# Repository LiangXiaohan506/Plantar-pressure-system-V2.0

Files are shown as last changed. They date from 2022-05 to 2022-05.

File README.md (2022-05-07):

# Plantar-pressure-system-v2.0
足底压力系统v2.0版本
内容包含硬件和软件
## 软件内容
DMA多通道读取ADC  
基于HAL库的MPU6050  
基于HAL库的OLED库  
串口配置  
定时器配置  
## 硬件部分
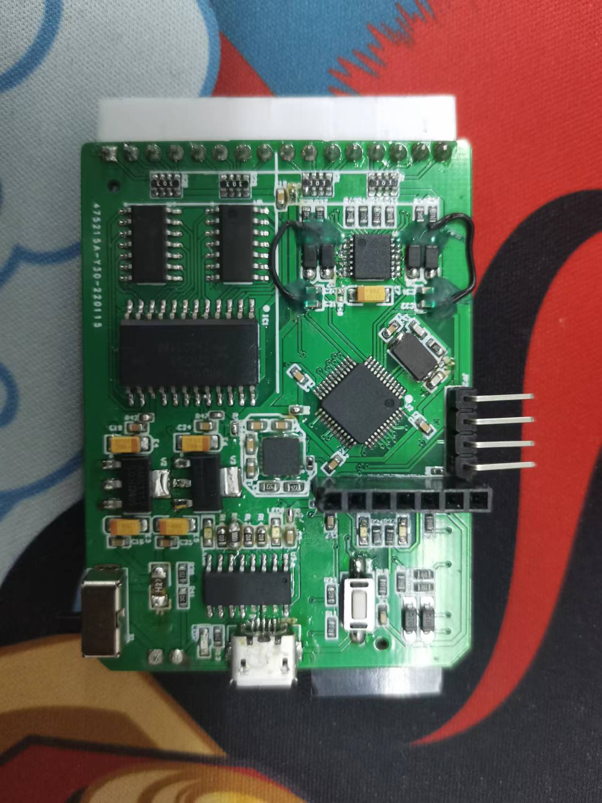
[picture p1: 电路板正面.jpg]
电路板正面
  

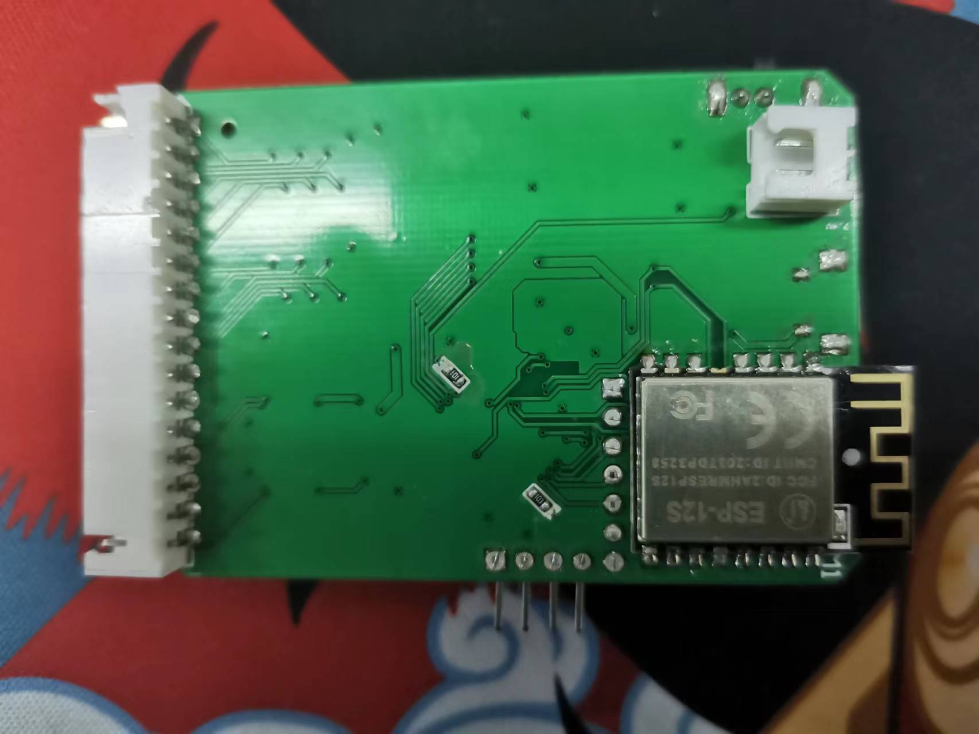
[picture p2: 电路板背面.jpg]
电路板背面


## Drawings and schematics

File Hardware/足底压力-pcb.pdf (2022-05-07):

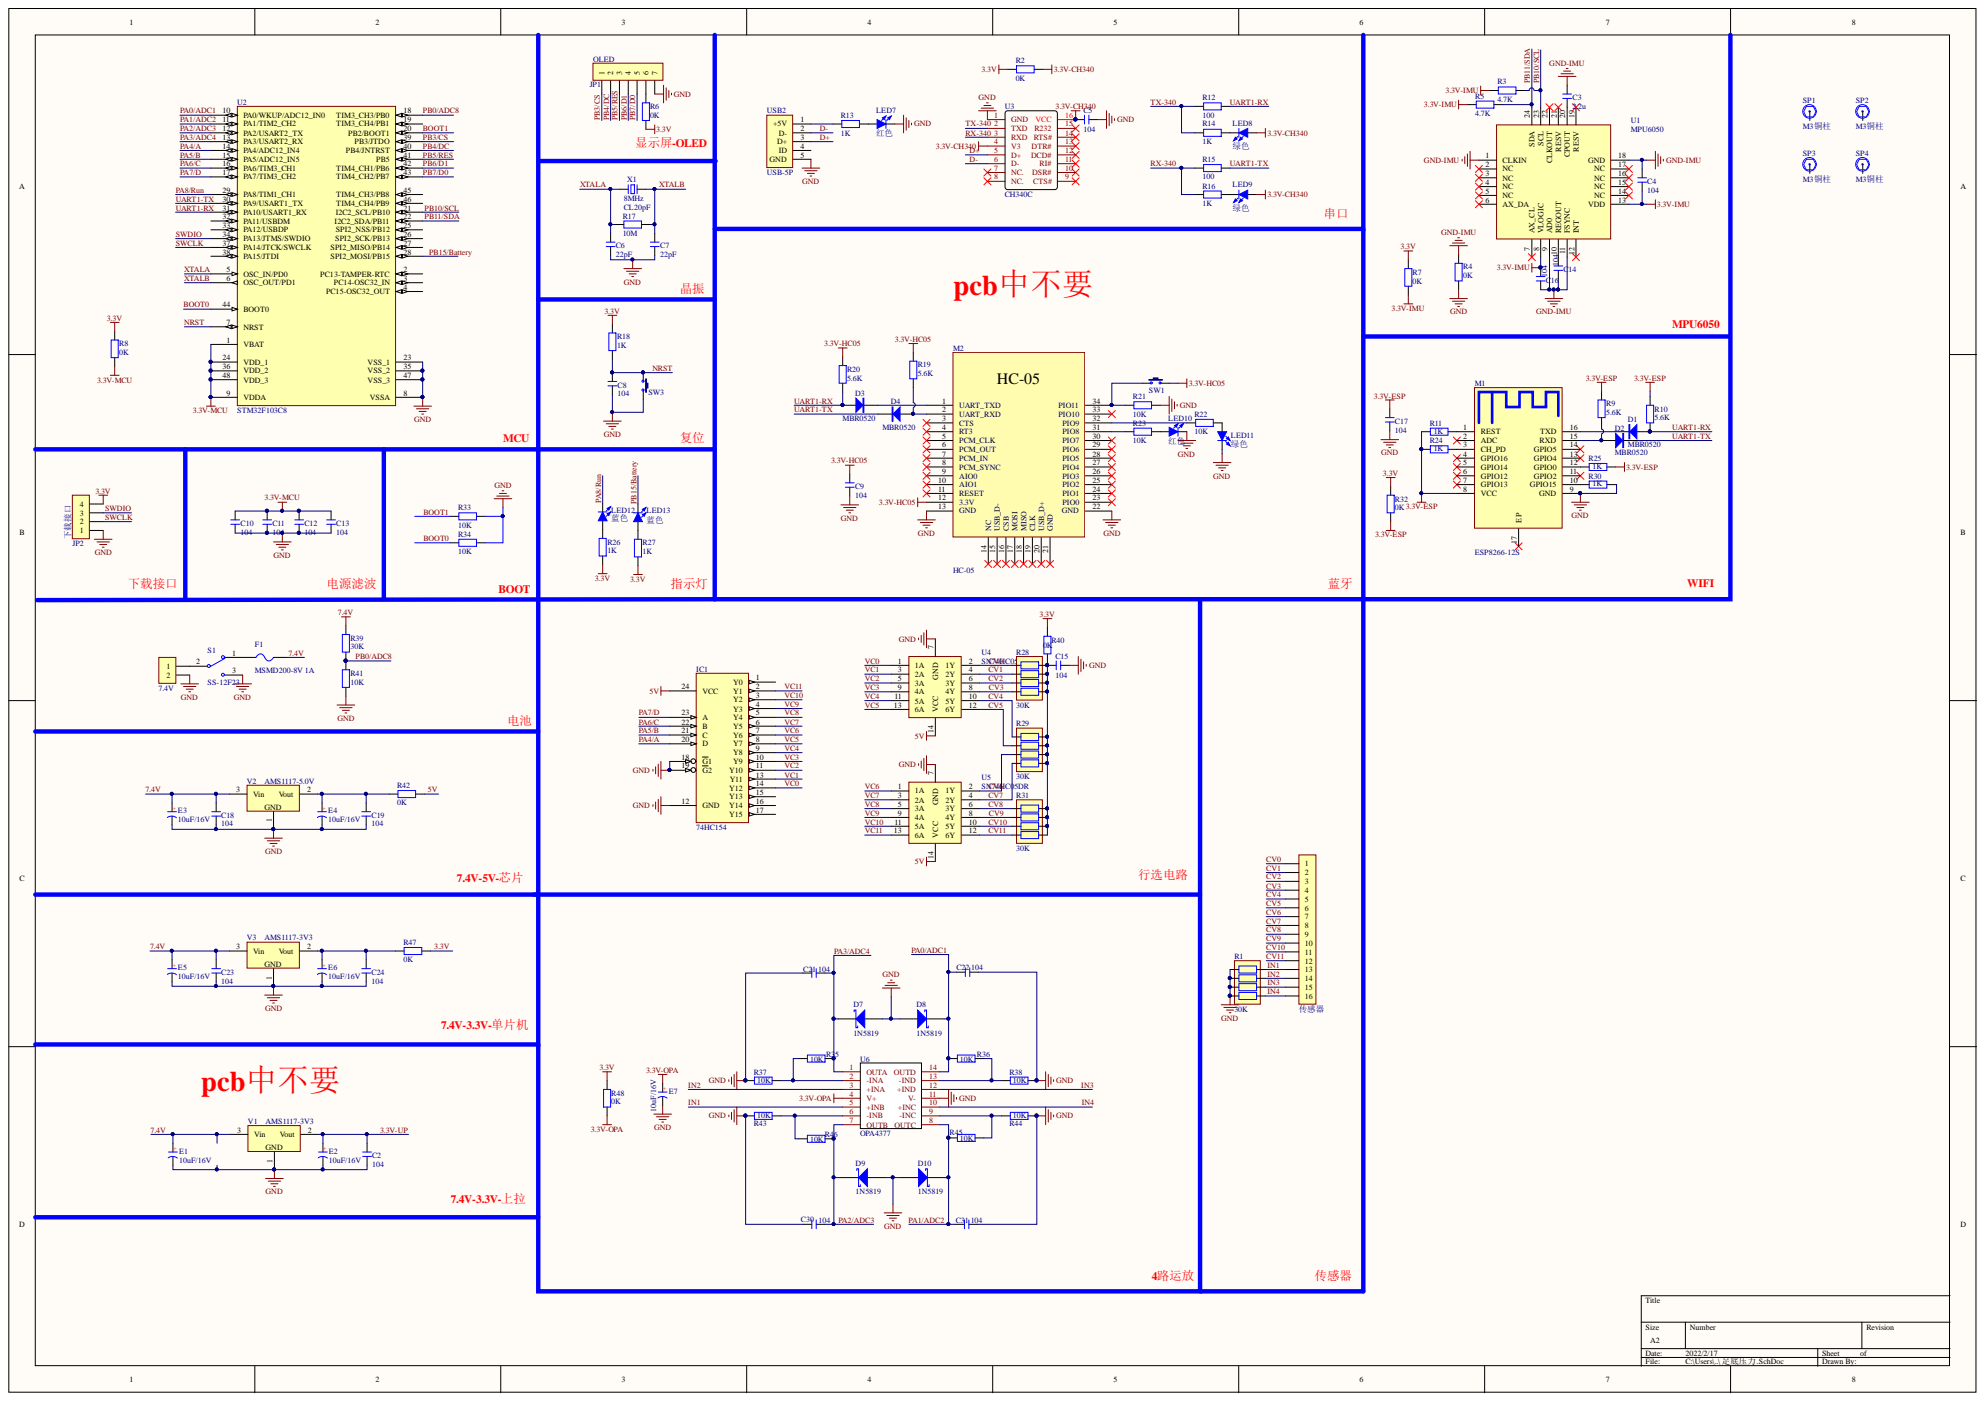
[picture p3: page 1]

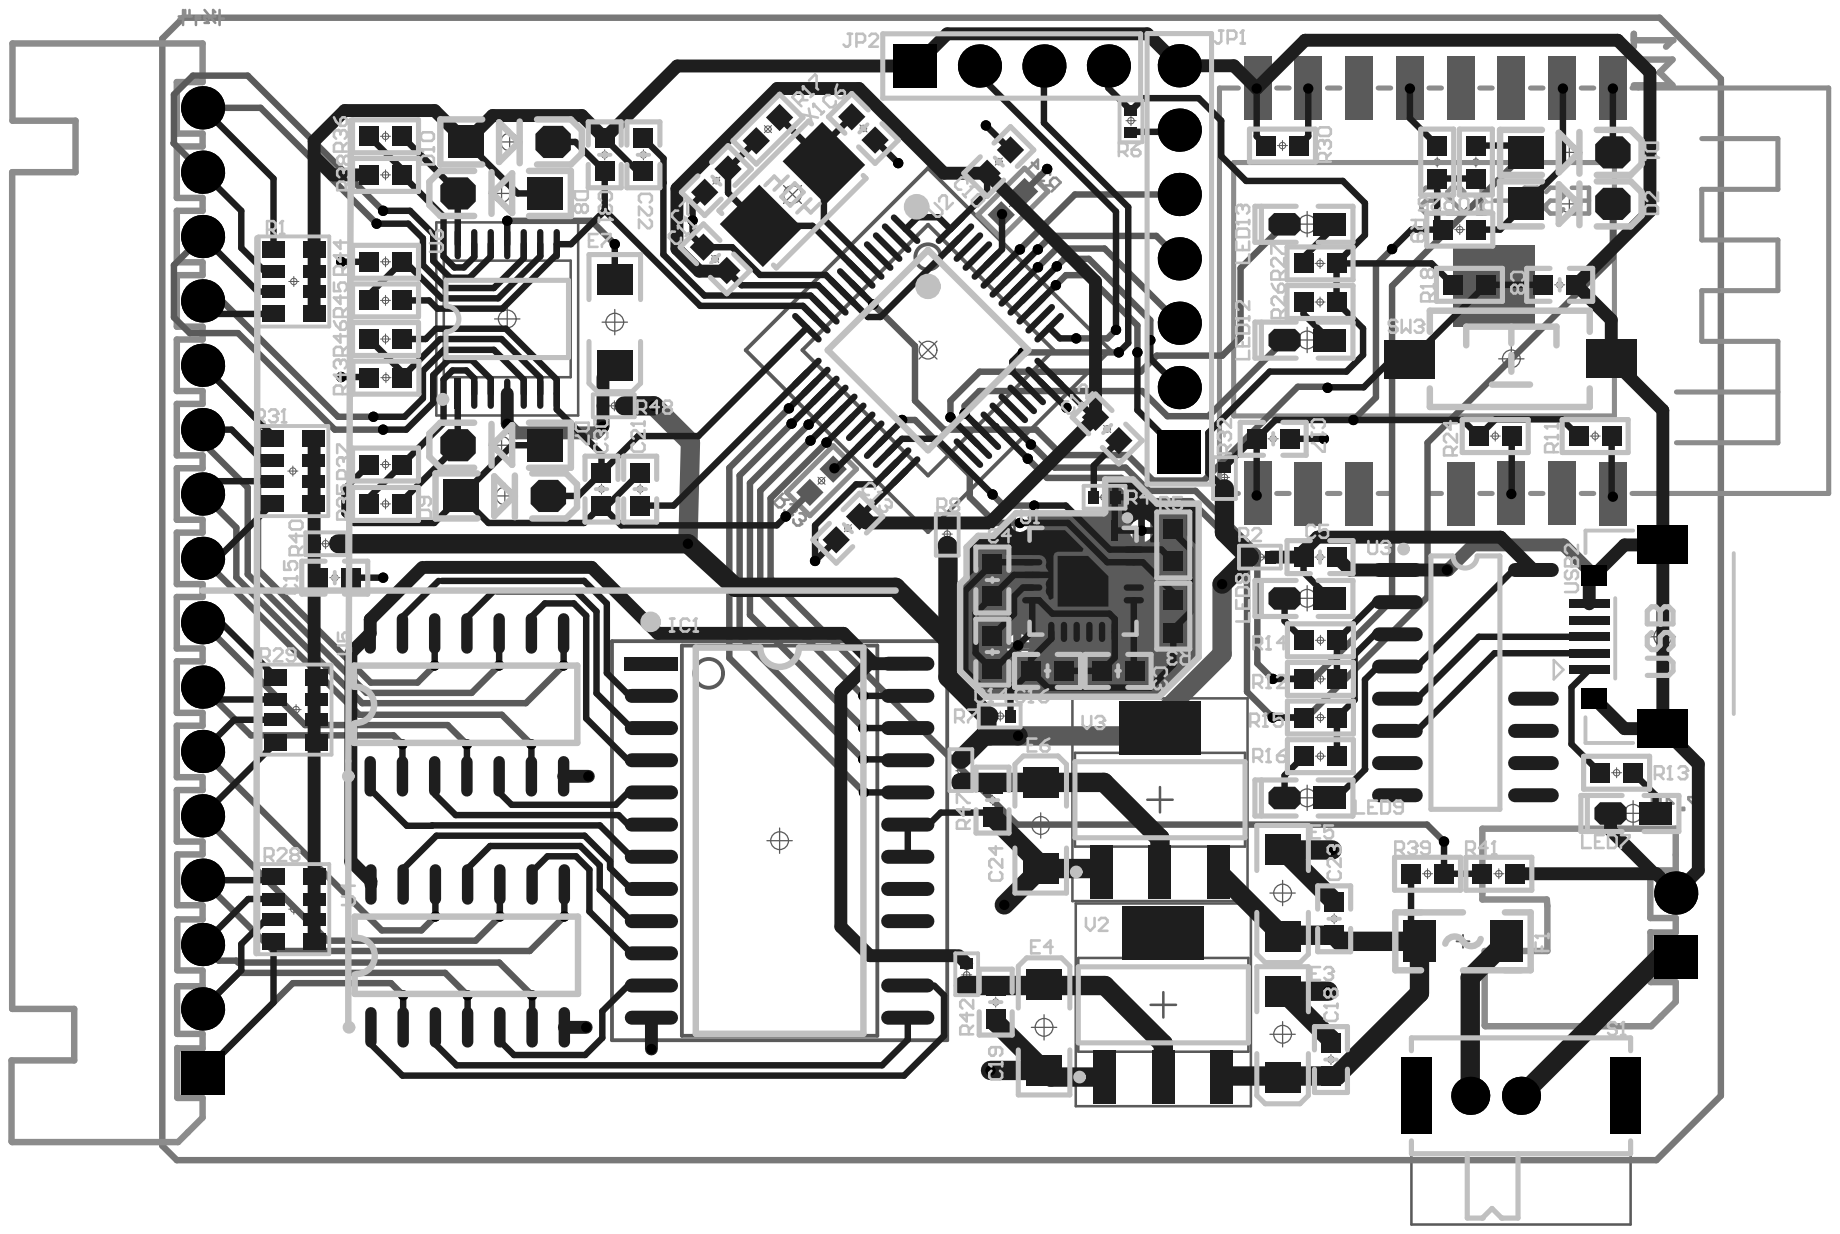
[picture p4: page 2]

Comment | Description | Designator | Footprint | LibRef | Quantity
HDR-1X2 | 2P接插件 | 7.4V | XH2.54-WI-2P | Header 2 | 1
104 | 贴片电容 | C2, C4, C5, C8, C10, C11, C12, C13, C14, C15, C16, C17, C18, C19, C21, C22, C23, C24, C30, C31 | C 0603_L | C | 20
2.2u | 贴片电容 | C3 | C 0603_L | C | 1
22pF | 贴片电容 | C6, C7 | C 0603_L | C | 2
104 | 贴片电容 | C9 | C 0805_L | C | 1
MBR0520 | 整流二极管 | D1, D2, D3, D4 | SOD-123 | 1N4007 | 4
1N5819 | 肖特基二极管 | D7, D8, D9, D10 | SOD-123 | 1N5819 | 4
10uF/16V | 贴片钽电容 | E1, E2, E3, E4, E5, E6, E7 | CD A(3216) | CT | 7
MSMD200-8V 1A | 贴片保险丝 | F1 | FU 1206 | FU | 1
74HC154 | 4线转16线译码器 | IC1 | SOP24_N | 74HC154 | 1
HDR-1X7 | 7P接插件 | JP1 | HDR2.54-M-LI-7P | Header 7 | 1
HDR-1X4 | 4P接插件 | JP2 | HDR2.54-LI-4P | Header 4 | 1
红色 | 贴片LED | LED7 | LED 0603R | LED-SMD | 1
绿色 | 贴片LED | LED8, LED9 | LED 0603G | LED-SMD | 2
红色 | 贴片LED | LED10 | LED 0805R | LED-SMD | 1
绿色 | 贴片LED | LED11 | LED 0805G | LED-SMD | 1
蓝色 | 贴片LED | LED12, LED13 | LED 0603B | LED-SMD | 2
ESP8266-12S | 立创商城 | M1 | ESP8266-12S | ESP8266-12S | 1
HC-05 | 串口蓝牙模块 | M2 | HC-05 | HC-05 | 1
30K | 贴片排阻 | R1, R28, R29, R31 | RCA-8P4R-0603 | R-8P4R | 4
0K | 贴片电阻 | R2, R4, R6, R7, R8, R32, R40, R42, R47, R48 | R 0402_L | R | 10
4.7K | 贴片电阻 | R3, R5 | R 0603_L | R | 2
5.6K | 贴片电阻 | R9, R10 | R 0603_L | R | 2
1K | 贴片电阻 | R11, R13, R14, R16, R18, R24, R25, R26, R27, R30 | R 0603_L | R | 10
100 | 贴片电阻 | R12, R15 | R 0603_L | R | 2
10M | 贴片电阻 | R17 | R 0603_L | R | 1
5.6K | 贴片电阻 | R19, R20 | R 0805_L | R | 2
10K | 贴片电阻 | R21, R22, R23 | R 0805_L | R | 3
10K | 贴片电阻 | R33, R34, R35, R36, R37, R38, R41, R43, R44, R45, R46 | R 0603_L | R | 11
30K | 贴片电阻 | R39 | R 0603_L | R | 1
SS-12F23 | 1路波动开关 | S1 | SK-12D07VG3 | SSW-1P | 1
M3铜柱 | 铜柱 | SP1, SP2, SP3, SP4 | M3x20_L | 铜柱小焊盘 | 4
3x6x5 | 3x6轻触开关 | SW1, SW3 | TSW SMD-3*6*2.5 | TSW 3x6 | 2
MPU6050 | 数字运动传感器 | U1 | QFN24 4x4_L | MPU6050 | 1
STM32F103C8 | Flaah:64/RAM:20/IO: 36 | U2 | LQFP48 7X7_L | STM32F103C8 | 1
CH340C | 串口芯片，无需外部 晶振 | U3 | SOP16 | CH340C | 1
SN74HC05DR | | U4, U5 | SOP14 | SN74HC05DR | 2
OPA4377 | 4路运放 | U6 | TSSOP14_L | OPA4377 | 1
USB-5P | 微型USB母座 | USB2 | USB-MICRO_A | USB-5P | 1
AMS1117-3V3 | 三端稳压芯片 | V1, V3 | SOT223_L | AMS1117 | 2
AMS1117-5.0V | 三端稳压芯片 | V2 | SOT223_L | AMS1117 | 1
8MHz | 2脚无源脚晶振 | X1 | OSC 5032-2P | XTAL-2P | 1
HDR-1X16 | 16P接插件 | 传感器 | XH2.54-WI-16P | Header 16 | 1

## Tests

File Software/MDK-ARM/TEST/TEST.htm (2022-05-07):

# Static Call Graph for image TEST\TEST.axf

#<CALLGRAPH># ARM Linker, 5060960: Last Updated: Mon Mar 07 09:23:30 2022

### Maximum Stack Usage = 408 bytes + Unknown(Functions without stacksize, Cycles, Untraceable Function Pointers)

### Call chain for Maximum Stack Depth:

__rt_entry_main ⇒ main ⇒ MPU6050_Get_Data ⇒ mpu_dmp_get_data ⇒ dmp_read_fifo ⇒ mpu_read_fifo_stream ⇒ mpu_reset_fifo ⇒ MPU_Write_Len ⇒ HAL_I2C_Mem_Write ⇒ I2C_RequestMemoryWrite ⇒ I2C_WaitOnMasterAddressFlagUntilTimeout

### Functions with no stack information

- __user_initial_stackheap

### Mutually Recursive functions

- ADC1_2_IRQHandler ⇒ ADC1_2_IRQHandler
- BusFault_Handler ⇒ BusFault_Handler
- HardFault_Handler ⇒ HardFault_Handler
- MemManage_Handler ⇒ MemManage_Handler
- NMI_Handler ⇒ NMI_Handler
- UsageFault_Handler ⇒ UsageFault_Handler

### Function Pointers

- ADC1_2_IRQHandler from startup_stm32f103xb.o(.text) referenced from startup_stm32f103xb.o(RESET)
- ADC_DMAConvCplt from stm32f1xx_hal_adc.o(i.ADC_DMAConvCplt) referenced from stm32f1xx_hal_adc.o(i.HAL_ADC_Start_DMA)
- ADC_DMAError from stm32f1xx_hal_adc.o(i.ADC_DMAError) referenced from stm32f1xx_hal_adc.o(i.HAL_ADC_Start_DMA)
- ADC_DMAHalfConvCplt from stm32f1xx_hal_adc.o(i.ADC_DMAHalfConvCplt) referenced from stm32f1xx_hal_adc.o(i.HAL_ADC_Start_DMA)
- BusFault_Handler from stm32f1xx_it.o(i.BusFault_Handler) referenced from startup_stm32f103xb.o(RESET)
- CAN1_RX1_IRQHandler from startup_stm32f103xb.o(.text) referenced from startup_stm32f103xb.o(RESET)
- CAN1_SCE_IRQHandler from startup_stm32f103xb.o(.text) referenced from startup_stm32f103xb.o(RESET)
- DMA1_Channel1_IRQHandler from stm32f1xx_it.o(i.DMA1_Channel1_IRQHandler) referenced from startup_stm32f103xb.o(RESET)
- DMA1_Channel2_IRQHandler from startup_stm32f103xb.o(.text) referenced from startup_stm32f103xb.o(RESET)
- DMA1_Channel3_IRQHandler from startup_stm32f103xb.o(.text) referenced from startup_stm32f103xb.o(RESET)
- DMA1_Channel4_IRQHandler from startup_stm32f103xb.o(.text) referenced from startup_stm32f103xb.o(RESET)
- DMA1_Channel5_IRQHandler from startup_stm32f103xb.o(.text) referenced from startup_stm32f103xb.o(RESET)
- DMA1_Channel6_IRQHandler from startup_stm32f103xb.o(.text) referenced from startup_stm32f103xb.o(RESET)
- DMA1_Channel7_IRQHandler from startup_stm32f103xb.o(.text) referenced from startup_stm32f103xb.o(RESET)
- DebugMon_Handler from stm32f1xx_it.o(i.DebugMon_Handler) referenced from startup_stm32f103xb.o(RESET)
- EXTI0_IRQHandler from startup_stm32f103xb.o(.text) referenced from startup_stm32f103xb.o(RESET)
- EXTI15_10_IRQHandler from startup_stm32f103xb.o(.text) referenced from startup_stm32f103xb.o(RESET)
- EXTI1_IRQHandler from startup_stm32f103xb.o(.text) referenced from startup_stm32f103xb.o(RESET)
- EXTI2_IRQHandler from startup_stm32f103xb.o(.text) referenced from startup_stm32f103xb.o(RESET)
- EXTI3_IRQHandler from startup_stm32f103xb.o(.text) referenced from startup_stm32f103xb.o(RESET)
- EXTI4_IRQHandler from startup_stm32f103xb.o(.text) referenced from startup_stm32f103xb.o(RESET)
- EXTI9_5_IRQHandler from startup_stm32f103xb.o(.text) referenced from startup_stm32f103xb.o(RESET)
- FLASH_IRQHandler from startup_stm32f103xb.o(.text) referenced from startup_stm32f103xb.o(RESET)
- HardFault_Handler from stm32f1xx_it.o(i.HardFault_Handler) referenced from startup_stm32f103xb.o(RESET)
- I2C1_ER_IRQHandler from startup_stm32f103xb.o(.text) referenced from startup_stm32f103xb.o(RESET)
- I2C1_EV_IRQHandler from startup_stm32f103xb.o(.text) referenced from startup_stm32f103xb.o(RESET)
- I2C2_ER_IRQHandler from startup_stm32f103xb.o(.text) referenced from startup_stm32f103xb.o(RESET)
- I2C2_EV_IRQHandler from startup_stm32f103xb.o(.text) referenced from startup_stm32f103xb.o(RESET)
- MemManage_Handler from stm32f1xx_it.o(i.MemManage_Handler) referenced from startup_stm32f103xb.o(RESET)
- NMI_Handler from stm32f1xx_it.o(i.NMI_Handler) referenced from startup_stm32f103xb.o(RESET)
- PVD_IRQHandler from startup_stm32f103xb.o(.text) referenced from startup_stm32f103xb.o(RESET)
- PendSV_Handler from stm32f1xx_it.o(i.PendSV_Handler) referenced from startup_stm32f103xb.o(RESET)
- RCC_IRQHandler from startup_stm32f103xb.o(.text) referenced from startup_stm32f103xb.o(RESET)
- RTC_Alarm_IRQHandler from startup_stm32f103xb.o(.text) referenced from startup_stm32f103xb.o(RESET)
- RTC_IRQHandler from startup_stm32f103xb.o(.text) referenced from startup_stm32f103xb.o(RESET)
- Reset_Handler from startup_stm32f103xb.o(.text) referenced from startup_stm32f103xb.o(RESET)
- SPI1_IRQHandler from startup_stm32f103xb.o(.text) referenced from startup_stm32f103xb.o(RESET)
- SPI2_IRQHandler from startup_stm32f103xb.o(.text) referenced from startup_stm32f103xb.o(RESET)
- SVC_Handler from stm32f1xx_it.o(i.SVC_Handler) referenced from startup_stm32f103xb.o(RESET)
- SysTick_Handler from stm32f1xx_it.o(i.SysTick_Handler) referenced from startup_stm32f103xb.o(RESET)
- SystemInit from system_stm32f1xx.o(i.SystemInit) referenced from startup_stm32f103xb.o(.text)
- TAMPER_IRQHandler from startup_stm32f103xb.o(.text) referenced from startup_stm32f103xb.o(RESET)
- TIM1_BRK_IRQHandler from startup_stm32f103xb.o(.text) referenced from startup_stm32f103xb.o(RESET)
- TIM1_CC_IRQHandler from startup_stm32f103xb.o(.text) referenced from startup_stm32f103xb.o(RESET)
- TIM1_TRG_COM_IRQHandler from startup_stm32f103xb.o(.text) referenced from startup_stm32f103xb.o(RESET)
- TIM1_UP_IRQHandler from stm32f1xx_it.o(i.TIM1_UP_IRQHandler) referenced from startup_stm32f103xb.o(RESET)
- TIM2_IRQHandler from startup_stm32f103xb.o(.text) referenced from startup_stm32f103xb.o(RESET)
- TIM3_IRQHandler from startup_stm32f103xb.o(.text) referenced from startup_stm32f103xb.o(RESET)
- TIM4_IRQHandler from startup_stm32f103xb.o(.text) referenced from startup_stm32f103xb.o(RESET)
- USART1_IRQHandler from startup_stm32f103xb.o(.text) referenced from startup_stm32f103xb.o(RESET)
- USART2_IRQHandler from startup_stm32f103xb.o(.text) referenced from startup_stm32f103xb.o(RESET)
- USART3_IRQHandler from startup_stm32f103xb.o(.text) referenced from startup_stm32f103xb.o(RESET)
- USBWakeUp_IRQHandler from startup_stm32f103xb.o(.text) referenced from startup_stm32f103xb.o(RESET)
- USB_HP_CAN1_TX_IRQHandler from startup_stm32f103xb.o(.text) referenced from startup_stm32f103xb.o(RESET)
- USB_LP_CAN1_RX0_IRQHandler from startup_stm32f103xb.o(.text) referenced from startup_stm32f103xb.o(RESET)
- UsageFault_Handler from stm32f1xx_it.o(i.UsageFault_Handler) referenced from startup_stm32f103xb.o(RESET)
- WWDG_IRQHandler from startup_stm32f103xb.o(.text) referenced from startup_stm32f103xb.o(RESET)
- __main from __main.o(!!!main) referenced from startup_stm32f103xb.o(.text)

### Global Symbols

__main (Thumb, 8 bytes, Stack size 0 bytes, __main.o(!!!main))

[Calls]

- >> __rt_entry
- >> __scatterload

__scatterload (Thumb, 0 bytes, Stack size unknown bytes, __scatter.o(!!!scatter))

[Called By]

- >> __main

__scatterload_rt2 (Thumb, 44 bytes, Stack size unknown bytes, __scatter.o(!!!scatter), UNUSED)

[Calls]

- >> __rt_entry

__scatterload_rt2_thumb_only (Thumb, 0 bytes, Stack size unknown bytes, __scatter.o(!!!scatter), UNUSED)

__scatterload_null (Thumb, 0 bytes, Stack size unknown bytes, __scatter.o(!!!scatter), UNUSED)

__scatterload_copy (Thumb, 26 bytes, Stack size unknown bytes, __scatter_copy.o(!!handler_copy), UNUSED)

[Calls]

- >> __scatterload_copy

[Called By]

- >> __scatterload_copy

__scatterload_zeroinit (Thumb, 28 bytes, Stack size unknown bytes, __scatter_zi.o(!!handler_zi), UNUSED)

__rt_lib_init (Thumb, 0 bytes, Stack size unknown bytes, libinit.o(.ARM.Collect$$libinit$$00000000))

[Called By]

- >> __rt_entry_li

__rt_lib_init_alloca_1 (Thumb, 0 bytes, Stack size unknown bytes, libinit2.o(.ARM.Collect$$libinit$$0000002E))

__rt_lib_init_argv_1 (Thumb, 0 bytes, Stack size unknown bytes, libinit2.o(.ARM.Collect$$libinit$$0000002C))

__rt_lib_init_atexit_1 (Thumb, 0 bytes, Stack size unknown bytes, libinit2.o(.ARM.Collect$$libinit$$0000001B))

__rt_lib_init_clock_1 (Thumb, 0 bytes, Stack size unknown bytes, libinit2.o(.ARM.Collect$$libinit$$00000021))

__rt_lib_init_cpp_1 (Thumb, 0 bytes, Stack size unknown bytes, libinit2.o(.ARM.Collect$$libinit$$00000032))

__rt_lib_init_exceptions_1 (Thumb, 0 bytes, Stack size unknown bytes, libinit2.o(.ARM.Collect$$libinit$$00000030))

__rt_lib_init_fp_1 (Thumb, 0 bytes, Stack size unknown bytes, libinit2.o(.ARM.Collect$$libinit$$00000002))

__rt_lib_init_fp_trap_1 (Thumb, 0 bytes, Stack size unknown bytes, libinit2.o(.ARM.Collect$$libinit$$0000001F))

__rt_lib_init_getenv_1 (Thumb, 0 bytes, Stack size unknown bytes, libinit2.o(.ARM.Collect$$libinit$$00000023))

__rt_lib_init_heap_1 (Thumb, 0 bytes, Stack size unknown bytes, libinit2.o(.ARM.Collect$$libinit$$0000000A))

__rt_lib_init_lc_collate_1 (Thumb, 0 bytes, Stack size unknown bytes, libinit2.o(.ARM.Collect$$libinit$$00000011))

__rt_lib_init_lc_ctype_1 (Thumb, 0 bytes, Stack size unknown bytes, libinit2.o(.ARM.Collect$$libinit$$00000013))

__rt_lib_init_lc_monetary_1 (Thumb, 0 bytes, Stack size unknown bytes, libinit2.o(.ARM.Collect$$libinit$$00000015))

__rt_lib_init_lc_numeric_1 (Thumb, 0 bytes, Stack size unknown bytes, libinit2.o(.ARM.Collect$$libinit$$00000017))

__rt_lib_init_lc_time_1 (Thumb, 0 bytes, Stack size unknown bytes, libinit2.o(.ARM.Collect$$libinit$$00000019))

__rt_lib_init_preinit_1 (Thumb, 0 bytes, Stack size unknown bytes, libinit2.o(.ARM.Collect$$libinit$$00000004))

__rt_lib_init_rand_1 (Thumb, 0 bytes, Stack size unknown bytes, libinit2.o(.ARM.Collect$$libinit$$0000000E))

__rt_lib_init_return (Thumb, 0 bytes, Stack size unknown bytes, libinit2.o(.ARM.Collect$$libinit$$00000033))

__rt_lib_init_signal_1 (Thumb, 0 bytes, Stack size unknown bytes, libinit2.o(.ARM.Collect$$libinit$$0000001D))

__rt_lib_init_stdio_1 (Thumb, 0 bytes, Stack size unknown bytes, libinit2.o(.ARM.Collect$$libinit$$00000025))

__rt_lib_init_user_alloc_1 (Thumb, 0 bytes, Stack size unknown bytes, libinit2.o(.ARM.Collect$$libinit$$0000000C))

__rt_lib_shutdown (Thumb, 0 bytes, Stack size unknown bytes, libshutdown.o(.ARM.Collect$$libshutdown$$00000000))

[Called By]

- >> __rt_exit_ls

__rt_lib_shutdown_cpp_1 (Thumb, 0 bytes, Stack size unknown bytes, libshutdown2.o(.ARM.Collect$$libshutdown$$00000004))

__rt_lib_shutdown_fini_1 (Thumb, 0 bytes, Stack size unknown bytes, libshutdown2.o(.ARM.Collect$$libshutdown$$00000002))

__rt_lib_shutdown_fp_trap_1 (Thumb, 0 bytes, Stack size unknown bytes, libshutdown2.o(.ARM.Collect$$libshutdown$$00000009))

__rt_lib_shutdown_heap_1 (Thumb, 0 bytes, Stack size unknown bytes, libshutdown2.o(.ARM.Collect$$libshutdown$$00000011))

__rt_lib_shutdown_return (Thumb, 0 bytes, Stack size unknown bytes, libshutdown2.o(.ARM.Collect$$libshutdown$$00000012))

__rt_lib_shutdown_signal_1 (Thumb, 0 bytes, Stack size unknown bytes, libshutdown2.o(.ARM.Collect$$libshutdown$$0000000C))

__rt_lib_shutdown_stdio_1 (Thumb, 0 bytes, Stack size unknown bytes, libshutdown2.o(.ARM.Collect$$libshutdown$$00000006))

__rt_lib_shutdown_user_alloc_1 (Thumb, 0 bytes, Stack size unknown bytes, libshutdown2.o(.ARM.Collect$$libshutdown$$0000000E))

__rt_entry (Thumb, 0 bytes, Stack size unknown bytes, __rtentry.o(.ARM.Collect$$rtentry$$00000000))

[Called By]

- >> __main
- >> __scatterload_rt2

__rt_entry_presh_1 (Thumb, 0 bytes, Stack size unknown bytes, __rtentry2.o(.ARM.Collect$$rtentry$$00000002))

__rt_entry_sh (Thumb, 0 bytes, Stack size unknown bytes, __rtentry4.o(.ARM.Collect$$rtentry$$00000004))

[Stack]

- Max Depth = 8 + Unknown Stack Size
- Call Chain = __rt_entry_sh ⇒ __user_setup_stackheap

[Calls]

- >> __user_setup_stackheap

__rt_entry_li (Thumb, 0 bytes, Stack size unknown bytes, __rtentry2.o(.ARM.Collect$$rtentry$$0000000A))

[Calls]

- >> __rt_lib_init

__rt_entry_postsh_1 (Thumb, 0 bytes, Stack size unknown bytes, __rtentry2.o(.ARM.Collect$$rtentry$$00000009))

__rt_entry_main (Thumb, 0 bytes, Stack size unknown bytes, __rtentry2.o(.ARM.Collect$$rtentry$$0000000D))

[Stack]

- Max Depth = 408 + Unknown Stack Size
- Call Chain = __rt_entry_main ⇒ main ⇒ MPU6050_Get_Data ⇒ mpu_dmp_get_data ⇒ dmp_read_fifo ⇒ mpu_read_fifo_stream ⇒ mpu_reset_fifo ⇒ MPU_Write_Len ⇒ HAL_I2C_Mem_Write ⇒ I2C_RequestMemoryWrite ⇒ I2C_WaitOnMasterAddressFlagUntilTimeout

[Calls]

- >> main
- >> exit

__rt_entry_postli_1 (Thumb, 0 bytes, Stack size unknown bytes, __rtentry2.o(.ARM.Collect$$rtentry$$0000000C))

__rt_exit (Thumb, 0 bytes, Stack size unknown bytes, rtexit.o(.ARM.Collect$$rtexit$$00000000))

[Called By]

- >> exit

__rt_exit_ls (Thumb, 0 bytes, Stack size unknown bytes, rtexit2.o(.ARM.Collect$$rtexit$$00000003))

[Calls]

- >> __rt_lib_shutdown

__rt_exit_prels_1 (Thumb, 0 bytes, Stack size unknown bytes, rtexit2.o(.ARM.Collect$$rtexit$$00000002))

__rt_exit_exit (Thumb, 0 bytes, Stack size unknown bytes, rtexit2.o(.ARM.Collect$$rtexit$$00000004))

[Calls]

- >> _sys_exit

Reset_Handler (Thumb, 8 bytes, Stack size 0 bytes, startup_stm32f103xb.o(.text))
[Address Reference Count : 1]

- startup_stm32f103xb.o(RESET)

ADC1_2_IRQHandler (Thumb, 0 bytes, Stack size 0 bytes, startup_stm32f103xb.o(.text))

[Calls]

- >> ADC1_2_IRQHandler

[Called By]

- >> ADC1_2_IRQHandler

[Address Reference Count : 1]

- startup_stm32f103xb.o(RESET)

CAN1_RX1_IRQHandler (Thumb, 0 bytes, Stack size 0 bytes, startup_stm32f103xb.o(.text))
[Address Reference Count : 1]

- startup_stm32f103xb.o(RESET)

CAN1_SCE_IRQHandler (Thumb, 0 bytes, Stack size 0 bytes, startup_stm32f103xb.o(.text))
[Address Reference Count : 1]

- startup_stm32f103xb.o(RESET)

DMA1_Channel2_IRQHandler (Thumb, 0 bytes, Stack size 0 bytes, startup_stm32f103xb.o(.text))
[Address Reference Count : 1]

- startup_stm32f103xb.o(RESET)

DMA1_Channel3_IRQHandler (Thumb, 0 bytes, Stack size 0 bytes, startup_stm32f103xb.o(.text))
[Address Reference Count : 1]

- startup_stm32f103xb.o(RESET)

DMA1_Channel4_IRQHandler (Thumb, 0 bytes, Stack size 0 bytes, startup_stm32f103xb.o(.text))
[Address Reference Count : 1]

- startup_stm32f103xb.o(RESET)

DMA1_Channel5_IRQHandler (Thumb, 0 bytes, Stack size 0 bytes, startup_stm32f103xb.o(.text))
[Address Reference Count : 1]

- startup_stm32f103xb.o(RESET)

DMA1_Channel6_IRQHandler (Thumb, 0 bytes, Stack size 0 bytes, startup_stm32f103xb.o(.text))
[Address Reference Count : 1]

- startup_stm32f103xb.o(RESET)

DMA1_Channel7_IRQHandler (Thumb, 0 bytes, Stack size 0 bytes, startup_stm32f103xb.o(.text))
[Address Reference Count : 1]

- startup_stm32f103xb.o(RESET)

EXTI0_IRQHandler (Thumb, 0 bytes, Stack size 0 bytes, startup_stm32f103xb.o(.text))
[Address Reference Count : 1]

- startup_stm32f103xb.o(RESET)

EXTI15_10_IRQHandler (Thumb, 0 bytes, Stack size 0 bytes, startup_stm32f103xb.o(.text))
[Address Reference Count : 1]

- startup_stm32f103xb.o(RESET)

EXTI1_IRQHandler (Thumb, 0 bytes, Stack size 0 bytes, startup_stm32f103xb.o(.text))
[Address Reference Count : 1]

- startup_stm32f103xb.o(RESET)

EXTI2_IRQHandler (Thumb, 0 bytes, Stack size 0 bytes, startup_stm32f103xb.o(.text))
[Address Reference Count : 1]

- startup_stm32f103xb.o(RESET)

EXTI3_IRQHandler (Thumb, 0 bytes, Stack size 0 bytes, startup_stm32f103xb.o(.text))
[Address Reference Count : 1]

- startup_stm32f103xb.o(RESET)

EXTI4_IRQHandler (Thumb, 0 bytes, Stack size 0 bytes, startup_stm32f103xb.o(.text))
[Address Reference Count : 1]

- startup_stm32f103xb.o(RESET)

EXTI9_5_IRQHandler (Thumb, 0 bytes, Stack size 0 bytes, startup_stm32f103xb.o(.text))
[Address Reference Count : 1]

- startup_stm32f103xb.o(RESET)

FLASH_IRQHandler (Thumb, 0 bytes, Stack size 0 bytes, startup_stm32f103xb.o(.text))
[Address Reference Count : 1]

- startup_stm32f103xb.o(RESET)

I2C1_ER_IRQHandler (Thumb, 0 bytes, Stack size 0 bytes, startup_stm32f103xb.o(.text))
[Address Reference Count : 1]

- startup_stm32f103xb.o(RESET)

I2C1_EV_IRQHandler (Thumb, 0 bytes, Stack size 0 bytes, startup_stm32f103xb.o(.text))
[Address Reference Count : 1]

- startup_stm32f103xb.o(RESET)

I2C2_ER_IRQHandler (Thumb, 0 bytes, Stack size 0 bytes, startup_stm32f103xb.o(.text))
[Address Reference Count : 1]

- startup_stm32f103xb.o(RESET)

I2C2_EV_IRQHandler (Thumb, 0 bytes, Stack size 0 bytes, startup_stm32f103xb.o(.text))
[Address Reference Count : 1]

- startup_stm32f103xb.o(RESET)

PVD_IRQHandler (Thumb, 0 bytes, Stack size 0 bytes, startup_stm32f103xb.o(.text))
[Address Reference Count : 1]

- startup_stm32f103xb.o(RESET)

RCC_IRQHandler (Thumb, 0 bytes, Stack size 0 bytes, startup_stm32f103xb.o(.text))
[Address Reference Count : 1]

- startup_stm32f103xb.o(RESET)

RTC_Alarm_IRQHandler (Thumb, 0 bytes, Stack size 0 bytes, startup_stm32f103xb.o(.text))
[Address Reference Count : 1]

- startup_stm32f103xb.o(RESET)

RTC_IRQHandler (Thumb, 0 bytes, Stack size 0 bytes, startup_stm32f103xb.o(.text))
[Address Reference Count : 1]

- startup_stm32f103xb.o(RESET)

SPI1_IRQHandler (Thumb, 0 bytes, Stack size 0 bytes, startup_stm32f103xb.o(.text))
[Address Reference Count : 1]

- startup_stm32f103xb.o(RESET)

SPI2_IRQHandler (Thumb, 0 bytes, Stack size 0 bytes, startup_stm32f103xb.o(.text))
[Address Reference Count : 1]

- startup_stm32f103xb.o(RESET)

TAMPER_IRQHandler (Thumb, 0 bytes, Stack size 0 bytes, startup_stm32f103xb.o(.text))
[Address Reference Count : 1]

- startup_stm32f103xb.o(RESET)

TIM1_BRK_IRQHandler (Thumb, 0 bytes, Stack size 0 bytes, startup_stm32f103xb.o(.text))
[Address Reference Count : 1]

- startup_stm32f103xb.o(RESET)

TIM1_CC_IRQHandler (Thumb, 0 bytes, Stack size 0 bytes, startup_stm32f103xb.o(.text))
[Address Reference Count : 1]

- startup_stm32f103xb.o(RESET)

TIM1_TRG_COM_IRQHandler (Thumb, 0 bytes, Stack size 0 bytes, startup_stm32f103xb.o(.text))
[Address Reference Count : 1]

- startup_stm32f103xb.o(RESET)

TIM2_IRQHandler (Thumb, 0 bytes, Stack size 0 bytes, startup_stm32f103xb.o(.text))
[Address Reference Count : 1]

- startup_stm32f103xb.o(RESET)

TIM3_IRQHandler (Thumb, 0 bytes, Stack size 0 bytes, startup_stm32f103xb.o(.text))
[Address Reference Count : 1]

- startup_stm32f103xb.o(RESET)

TIM4_IRQHandler (Thumb, 0 bytes, Stack size 0 bytes, startup_stm32f103xb.o(.text))
[Address Reference Count : 1]

- startup_stm32f103xb.o(RESET)

USART1_IRQHandler (Thumb, 0 bytes, Stack size 0 bytes, startup_stm32f103xb.o(.text))
[Address Reference Count : 1]

- startup_stm32f103xb.o(RESET)

USART2_IRQHandler (Thumb, 0 bytes, Stack size 0 bytes, startup_stm32f103xb.o(.text))
[Address Reference Count : 1]

- startup_stm32f103xb.o(RESET)

USART3_IRQHandler (Thumb, 0 bytes, Stack size 0 bytes, startup_stm32f103xb.o(.text))
[Address Reference Count : 1]

- startup_stm32f103xb.o(RESET)

USBWakeUp_IRQHandler (Thumb, 0 bytes, Stack size 0 bytes, startup_stm32f103xb.o(.text))
[Address Reference Count : 1]

- startup_stm32f103xb.o(RESET)

USB_HP_CAN1_TX_IRQHandler (Thumb, 0 bytes, Stack size 0 bytes, startup_stm32f103xb.o(.text))
[Address Reference Count : 1]

- startup_stm32f103xb.o(RESET)

USB_LP_CAN1_RX0_IRQHandler (Thumb, 0 bytes, Stack size 0 bytes, startup_stm32f103xb.o(.text))
[Address Reference Count : 1]

- startup_stm32f103xb.o(RESET)

WWDG_IRQHandler (Thumb, 0 bytes, Stack size 0 bytes, startup_stm32f103xb.o(.text))
[Address Reference Count : 1]

- startup_stm32f103xb.o(RESET)

__user_initial_stackheap (Thumb, 0 bytes, Stack size unknown bytes, startup_stm32f103xb.o(.text))

[Called By]

- >> __user_setup_stackheap

__aeabi_ldivmod (Thumb, 0 bytes, Stack size 8 bytes, llsdiv.o(.text))

[Stack]

- Max Depth = 8
- Call Chain = __aeabi_ldivmod

[Called By]

- >> get_st_biases

_ll_sdiv (Thumb, 72 bytes, Stack size 8 bytes, llsdiv.o(.text), UNUSED)

[Calls]

- >> __aeabi_uldivmod

memcmp (Thumb, 88 bytes, Stack size 8 bytes, memcmp.o(.text))

[Stack]

- Max Depth = 8
- Call Chain = memcmp

[Called By]

- >> mpu_load_firmware

__aeabi_memset (Thumb, 16 bytes, Stack size 0 bytes, aeabi_memset.o(.text))

[Calls]

- >> _memset

[Called By]

- >> dmp_enable_lp_quat
- >> dmp_enable_6x_lp_quat

__aeabi_memclr4 (Thumb, 0 bytes, Stack size 4 bytes, rt_memclr_w.o(.text))

[Stack]

- Max Depth = 4
- Call Chain = __aeabi_memclr4

[Called By]

- >> SystemClock_Config

__aeabi_memclr8 (Thumb, 0 bytes, Stack size 4 bytes, rt_memclr_w.o(.text), UNUSED)

__rt_memclr_w (Thumb, 78 bytes, Stack size 4 bytes, rt_memclr_w.o(.text), UNUSED)

_memset_w (Thumb, 0 bytes, Stack size unknown bytes, rt_memclr_w.o(.text), UNUSED)

[Called By]

- >> __rt_memclr

__use_two_region_memory (Thumb, 2 bytes, Stack size 0 bytes, heapauxi.o(.text), UNUSED)

__rt_heap_escrow$2region (Thumb, 2 bytes, Stack size 0 bytes, heapauxi.o(.text), UNUSED)

__rt_heap_expand$2region (Thumb, 2 bytes, Stack size 0 bytes, heapauxi.o(.text), UNUSED)

__aeabi_uldivmod (Thumb, 0 bytes, Stack size 48 bytes, lludivv7m.o(.text), UNUSED)

[Called By]

- >> _ll_sdiv

_ll_udiv (Thumb, 238 bytes, Stack size 48 bytes, lludivv7m.o(.text), UNUSED)

__read_errno (Thumb, 10 bytes, Stack size 8 bytes, _rserrno.o(.text), UNUSED)

[Calls]

- >> __aeabi_errno_addr

__set_errno (Thumb, 12 bytes, Stack size 8 bytes, _rserrno.o(.text))

[Stack]

- Max Depth = 8
- Call Chain = __set_errno

[Calls]

- >> __aeabi_errno_addr

[Called By]

- >> sqrt
- >> atan2
- >> asin

__aeabi_memclr (Thumb, 0 bytes, Stack size 0 bytes, rt_memclr.o(.text), UNUSED)

__rt_memclr (Thumb, 68 bytes, Stack size 0 bytes, rt_memclr.o(.text), UNUSED)

[Calls]

- >> _memset_w

_memset (Thumb, 0 bytes, Stack size unknown bytes, rt_memclr.o(.text))

[Called By]

- >> __aeabi_memset

__aeabi_errno_addr (Thumb, 8 bytes, Stack size 0 bytes, rt_errno_addr_intlibspace.o(.text))

[Called By]

- >> __set_errno
- >> __read_errno

__errno$intlibspace (Thumb, 0 bytes, Stack size 0 bytes, rt_errno_addr_intlibspace.o(.text), UNUSED)

__rt_errno_addr$intlibspace (Thumb, 0 bytes, Stack size 0 bytes, rt_errno_addr_intlibspace.o(.text), UNUSED)

__user_libspace (Thumb, 8 bytes, Stack size 0 bytes, libspace.o(.text), UNUSED)

__user_perproc_libspace (Thumb, 0 bytes, Stack size 0 bytes, libspace.o(.text))

[Called By]

- >> __user_setup_stackheap

__user_perthread_libspace (Thumb, 0 bytes, Stack size 0 bytes, libspace.o(.text), UNUSED)

__user_setup_stackheap (Thumb, 74 bytes, Stack size 8 bytes, sys_stackheap_outer.o(.text))

[Stack]

- Max Depth = 8 + Unknown Stack Size
- Call Chain = __user_setup_stackheap

[Calls]

- >> __user_initial_stackheap
- >> __user_perproc_libspace

[Called By]

- >> __rt_entry_sh

exit (Thumb, 18 bytes, Stack size 8 bytes, exit.o(.text))

[Stack]

- Max Depth = 8 + Unknown Stack Size
- Call Chain = exit

[Calls]

- >> __rt_exit

[Called By]

- >> __rt_entry_main

_sys_exit (Thumb, 8 bytes, Stack size 0 bytes, sys_exit.o(.text))

[Called By]

- >> __rt_exit_exit

__I$use$semihosting (Thumb, 0 bytes, Stack size 0 bytes, use_no_semi.o(.text), UNUSED)

__use_no_semihosting_swi (Thumb, 2 bytes, Stack size 0 bytes, use_no_semi.o(.text), UNUSED)

__semihosting_library_function (Thumb, 0 bytes, Stack size unknown bytes, indicate_semi.o(.text), UNUSED)

ADC_ConversionStop_Disable (Thumb, 86 bytes, Stack size 16 bytes, stm32f1xx_hal_adc.o(i.ADC_ConversionStop_Disable))

[Stack]

- Max Depth = 16
- Call Chain = ADC_ConversionStop_Disable

[Calls]

- >> HAL_GetTick

[Called By]

- >> HAL_ADC_Init
- >> HAL_ADCEx_Calibration_Start

ADC_DMAConvCplt (Thumb, 78 bytes, Stack size 8 bytes, stm32f1xx_hal_adc.o(i.ADC_DMAConvCplt))

[Stack]

- Max Depth = 8
- Call Chain = ADC_DMAConvCplt

[Calls]

- >> HAL_ADC_ConvCpltCallback

[Address Reference Count : 1]

- stm32f1xx_hal_adc.o(i.HAL_ADC_Start_DMA)

ADC_DMAError (Thumb, 26 bytes, Stack size 8 bytes, stm32f1xx_hal_adc.o(i.ADC_DMAError))

[Stack]

- Max Depth = 8
- Call Chain = ADC_DMAError

[Calls]

- >> HAL_ADC_ErrorCallback

[Address Reference Count : 1]

- stm32f1xx_hal_adc.o(i.HAL_ADC_Start_DMA)

ADC_DMAHalfConvCplt (Thumb, 10 bytes, Stack size 8 bytes, stm32f1xx_hal_adc.o(i.ADC_DMAHalfConvCplt))

[Stack]
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

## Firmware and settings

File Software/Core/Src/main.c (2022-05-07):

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
/* Includes ------------------------------------------------------------------*/
#include "main.h"
#include "adc.h"
#include "dma.h"
#include "i2c.h"
#include "tim.h"
#include "usart.h"
#include "gpio.h"

/* USER CODE BEGIN Includes */
#include "oled.h"
#include "mpu6050.h"
#include "inv_mpu.h"
#include "inv_mpu_dmp_motion_driver.h" 
/* USER CODE END Includes */


/* USER CODE BEGIN PV */
extern uint16_t Battery;//电池电压值
uint16_t ADC_ConvertedValue[4];//DMA存储数据的容器
uint16_t VoltageS[12][4];//阵列传感器的数据
volatile float pitch,roll,yaw;//欧拉角
uint8_t Row_list[4] = {1,0,3,2};//列顺序
//******************{7,6,8,5,9,4,10,3,11,2,12,1}//经过调试将前两列后最后，我也不知道为啥，但是work了！！
uint8_t Row_A[12] = {1,0,0,1,1,0,0, 1,1, 0,0, 1};
uint8_t Row_B[12] = {1,1,0,0,0,0,1, 1,1, 1,0, 0};
uint8_t Row_C[12] = {1,1,0,1,0,1,0, 0,0, 0,1, 0};
uint8_t Row_D[12] = {0,0,1,0,1,0,1, 0,1, 0,1, 0};//1~12
uint8_t MPU6050_Data_OK;//MPU6050数据可用标志位
uint8_t uart_buf_bat[2] = {0x00, 0x00};//串口发送电池电压容器
uint8_t uart_buf_v[2] = {0x00, 0x00};//串口发送阵列电压容器
uint8_t uart_buf_imu[3] = {0x00, 0x00, 0x00};//串口发送陀螺仪数据容器
/* USER CODE END PV */

void SystemClock_Config(void);
/* USER CODE BEGIN PFP */
void Adc_Battery(void);
void DMA_Adc_collect(void);
void delay_us(uint32_t us);
void MPU6050_Get_Data(void);
void OLED_Show(void);
void Data_upload(void);
/* USER CODE END PFP */

/**
  * @brief  The application entry point.
  * @retval int
  */
int main(void)
{
  /* MCU Configuration--------------------------------------------------------*/

  /* Reset of all peripherals, Initializes the Flash interface and the Systick. */
  HAL_Init();

  /* Configure the system clock */
  SystemClock_Config();

  /* Initialize all configured peripherals */
  MX_GPIO_Init();
  MX_ADC2_Init();
  MX_DMA_Init();
  MX_ADC1_Init();
  MX_I2C2_Init();
  MX_USART1_UART_Init();
  MX_TIM1_Init();
  /* USER CODE BEGIN 2 */
	HAL_TIM_Base_Start_IT(&htim1);
	
	HAL_ADCEx_Calibration_Start(&hadc1);//开启ADC校准
	HAL_ADCEx_Calibration_Start(&hadc2);
	
	OLED_Init();
	OLED_ColorTurn(0);//0正常显示，1 反色显示
  OLED_DisplayTurn(0);//0正常显示 1 屏幕翻转显示
	OLED_Refresh();

	MPU_Init();//初始化MPU6050
	
	while(mpu_dmp_init())
	{
	}//等待mpu_dmp初始化
	
  /* USER CODE END 2 */

  /* Infinite loop */
  /* USER CODE BEGIN WHILE */
  while (1)
  {
		DMA_Adc_collect();//获取压力传感器电压
		MPU6050_Get_Data();//获取陀螺仪数据
		OLED_Show();//数据展示
		Data_upload();//数据上传
		
		HAL_GPIO_TogglePin(GPIOA,Run_Pin);
    /* USER CODE END WHILE */

    /* USER CODE BEGIN 3 */
  }
  /* USER CODE END 3 */
}

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
/* USER CODE BEGIN 4 */
//=============================================================================
//函数名称：Adc_Battery()
//功能概要：读取电池电压值
//参数说明：无
//函数返回：无
//=============================================================================
void Adc_Battery(void)
{
	HAL_ADC_Start(&hadc2);//启动ADC装换
	HAL_ADC_PollForConversion(&hadc2, 5);//等待转换完成，第二个参数表示超时时间，单位ms.
	if(HAL_IS_BIT_SET(HAL_ADC_GetState(&hadc2), HAL_ADC_STATE_REG_EOC))
	{
		Battery = HAL_ADC_GetValue(&hadc2);//读取ADC转换数据，数据为12位
		Battery = (float)Battery*(3.300/4096)*1000;
		Battery = Battery*4.0;
	}
}

//=============================================================================
//函数名称：DMA_Adc_collect()
//功能概要：读取DMA_AD值
//参数说明：无
//函数返回：无
//=============================================================================
void DMA_Adc_collect(void)
{
	uint8_t r,i,m;
	
	for(r=0; r<12; r++)//行
	{
		HAL_GPIO_WritePin(GPIOA, R_A_Pin, Row_A[0]);
		HAL_GPIO_WritePin(GPIOA, R_B_Pin, Row_B[0]);
		HAL_GPIO_WritePin(GPIOA, R_C_Pin, Row_C[0]);
		HAL_GPIO_WritePin(GPIOA, R_D_Pin, Row_D[0]);
		delay_us(50);
		HAL_ADC_Start_DMA(&hadc1, (uint32_t*)&ADC_ConvertedValue, 4);
		delay_us(50);
		for(i=0;i<4;i++)
		{
			m = Row_list[i];//列顺序
			VoltageS[r][m]=(uint16_t)((float)ADC_ConvertedValue[i]/4096*3.300*1000)%10000;
		}
	}
}

//=============================================================================
//函数名称：delay_us()
//功能概要：延时函数（单位us）
//参数说明：无
//函数返回：无
//=============================================================================
void delay_us(uint32_t us)
{
    uint32_t delay = (HAL_RCC_GetHCLKFreq() / 4000000 * us);
    while (delay--)
	{
		;
	}
}

//=============================================================================
//函数名称：MPU6050_Get_Data()
//功能概要：陀螺仪数据读取
//参数说明：无
//函数返回：无
//=============================================================================
void MPU6050_Get_Data(void)
{
	if(mpu_dmp_get_data(&pitch,&roll,&yaw)==0)
	{ 
		MPU6050_Data_OK = 1;
		uart_buf_imu[0] = pitch;
		uart_buf_imu[1] = roll;
		uart_buf_imu[2] = yaw;
	}
	else
	{
		MPU6050_Data_OK = 0;
	}
}	

//=============================================================================
//函数名称：OLED_Show()
//功能概要：OLED展示
//参数说明：无
//函数返回：无
//=============================================================================
void OLED_Show(void)
{
	OLED_ShowString(0,0,"Battery",8,1);
	OLED_ShowNum(1,8,Battery,4,8,1);
	OLED_ShowNum(1,16,VoltageS[1][0],4,8,1);
	OLED_ShowNum(1,24,VoltageS[1][1],4,8,1);
	OLED_ShowNum(1,32,VoltageS[1][2],4,8,1);
	OLED_ShowNum(1,40,VoltageS[1][3],4,8,1);
	
	if(MPU6050_Data_OK)
	{
		OLED_ShowString(50,0,"IMU",8,1);
		OLED_ShowNum(50,8,pitch,4,8,1);
		OLED_ShowNum(50,16,roll,4,8,1);
		OLED_ShowNum(50,24,yaw,4,8,1);
	}
		
	OLED_Refresh();
}	

//=============================================================================
//函数名称：Data_upload()
//功能概要：将数据通过串口上传到上位机
//参数说明：无
//函数返回：无
//=============================================================================
void Data_upload(void)
{
	uint8_t i, j;
	
	uart_buf_bat[0] = Battery>>8;//数据高位
	uart_buf_bat[1] = Battery&0xff;//数据低位
	HAL_UART_Transmit(&huart1, (uint8_t *)uart_buf_bat, 2, 1);//上传电池电压数据
	
	HAL_UART_Transmit(&huart1, (uint8_t *)uart_buf_imu, 3, 1);//上传陀螺仪数据
	
	for(i=0; i<4; i++)//列
	{
		for(j=0; j<12; j++)//行
		{
			uart_buf_v[0] = VoltageS[j][i]>>8;//数据高位
			uart_buf_v[0] = VoltageS[j][i]&0xff;//数据低位
			HAL_UART_Transmit(&huart1, (uint8_t *)uart_buf_v, 2, 1);//上传阵列数据
		}
	}
}
/* USER CODE END 4 */
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


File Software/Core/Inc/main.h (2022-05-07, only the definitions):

#define R_D_Pin GPIO_PIN_4
#define R_D_GPIO_Port GPIOA
#define R_C_Pin GPIO_PIN_5
#define R_C_GPIO_Port GPIOA
#define R_B_Pin GPIO_PIN_6
#define R_B_GPIO_Port GPIOA
#define R_A_Pin GPIO_PIN_7
#define R_A_GPIO_Port GPIOA
#define Battery_Pin GPIO_PIN_0
#define Battery_GPIO_Port GPIOB
#define Tongxin_Pin GPIO_PIN_15
#define Tongxin_GPIO_Port GPIOB
#define Run_Pin GPIO_PIN_8
#define Run_GPIO_Port GPIOA
#define OLED_CS_Pin GPIO_PIN_3
#define OLED_CS_GPIO_Port GPIOB
#define OLED_DC_Pin GPIO_PIN_4
#define OLED_DC_GPIO_Port GPIOB
#define OLED_RES_Pin GPIO_PIN_5
#define OLED_RES_GPIO_Port GPIOB
#define OLED_D1_Pin GPIO_PIN_6
#define OLED_D1_GPIO_Port GPIOB
#define OLED_D0_Pin GPIO_PIN_7
#define OLED_D0_GPIO_Port GPIOB

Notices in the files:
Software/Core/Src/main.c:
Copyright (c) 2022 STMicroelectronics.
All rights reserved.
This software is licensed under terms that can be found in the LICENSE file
